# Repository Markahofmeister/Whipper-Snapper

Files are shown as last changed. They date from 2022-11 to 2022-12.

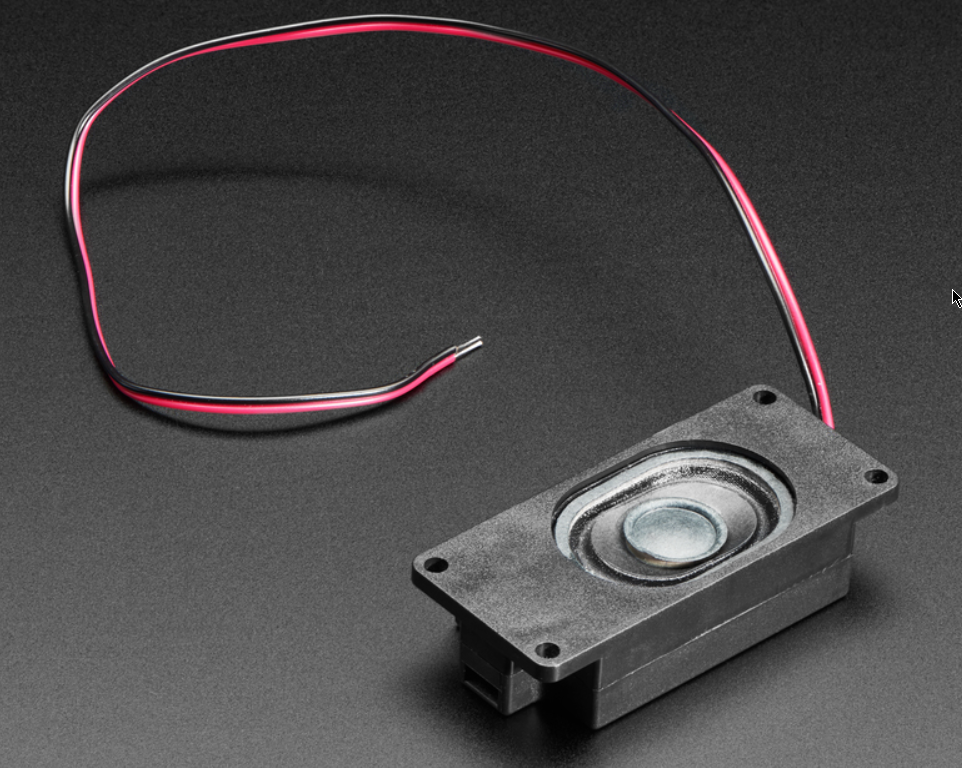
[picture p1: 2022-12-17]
media/3W-speaker.png

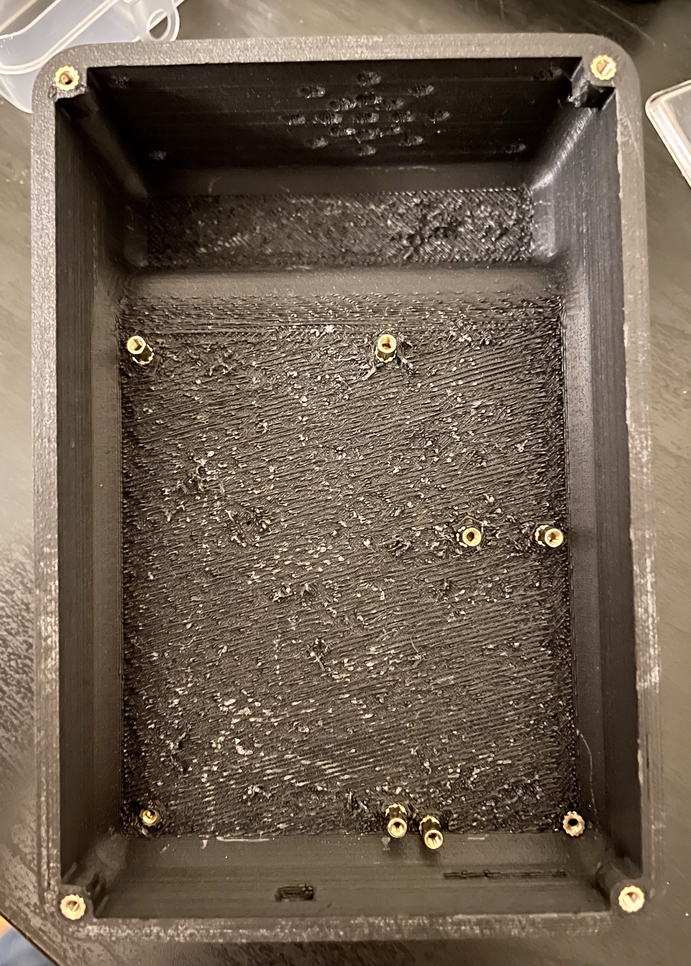
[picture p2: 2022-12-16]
media/standoffs.jpg

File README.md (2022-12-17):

# Whipper-Snapper

```bash
├───fab                     //includes mechanical fabrication .stl and .step
│   └───imported
├───figures                 //diagrams and datasheets
├───media                   //images & videos
├───software                //all Arduino code
│   ├───I2S-test-mono
│   ├───I2S-test-WAV
│   ├───src                 //main code on Arduino
│   └───wav-files
└───Whipper-Snapper-PCB     //All Altium files
```

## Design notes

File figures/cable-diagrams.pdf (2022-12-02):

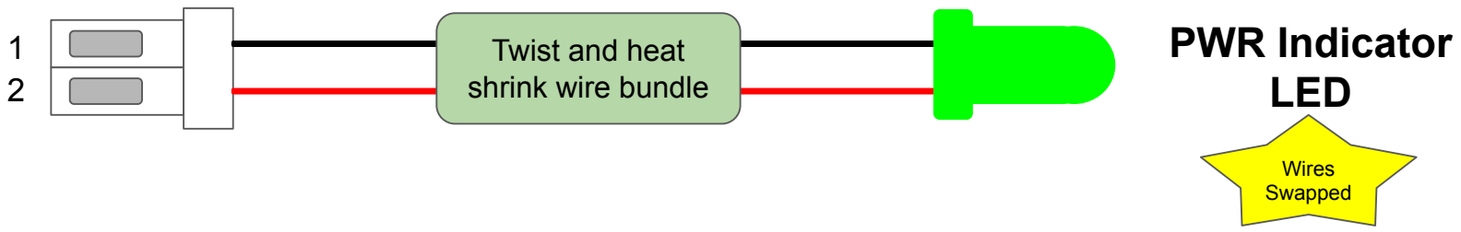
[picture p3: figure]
PWR Indicator LED; Twist and heat shrink wire bundle; Wires Swapped

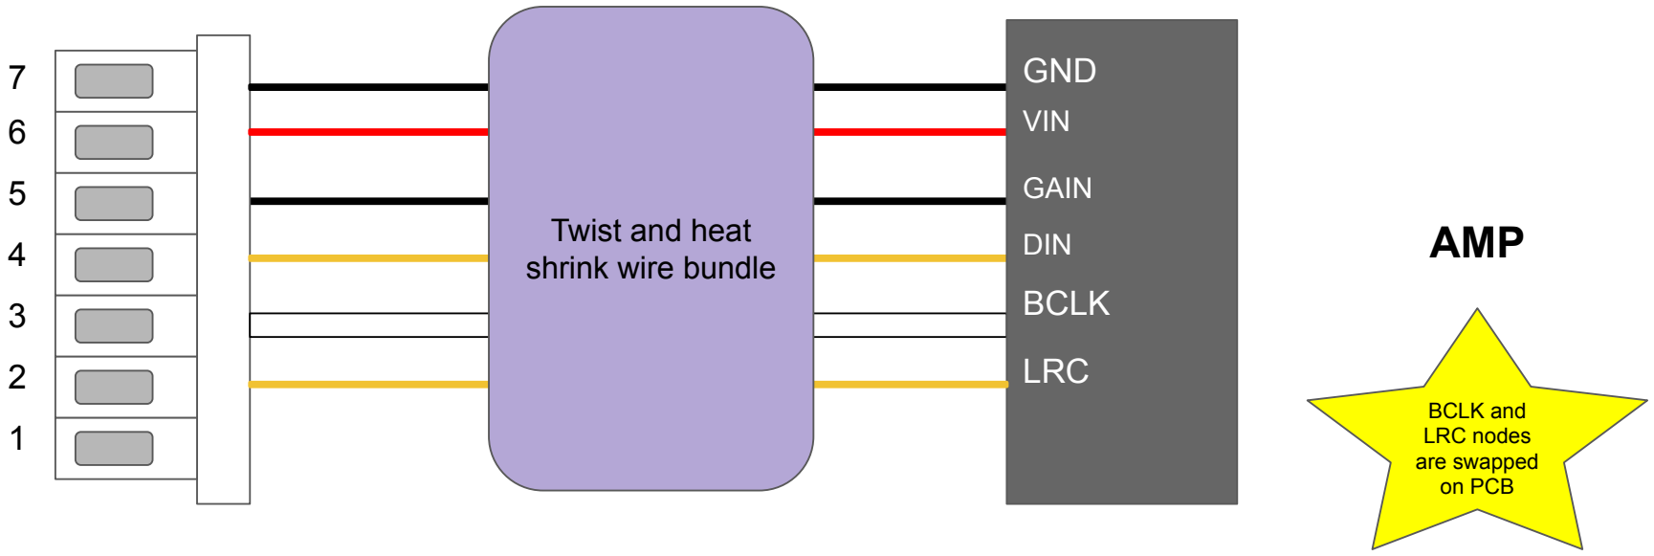
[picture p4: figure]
AMP; GND; LRC; DIN; BCLK; GAIN; VIN; Twist and heat shrink wire bundle; BCLK and LRC nodes are swapped on PCB

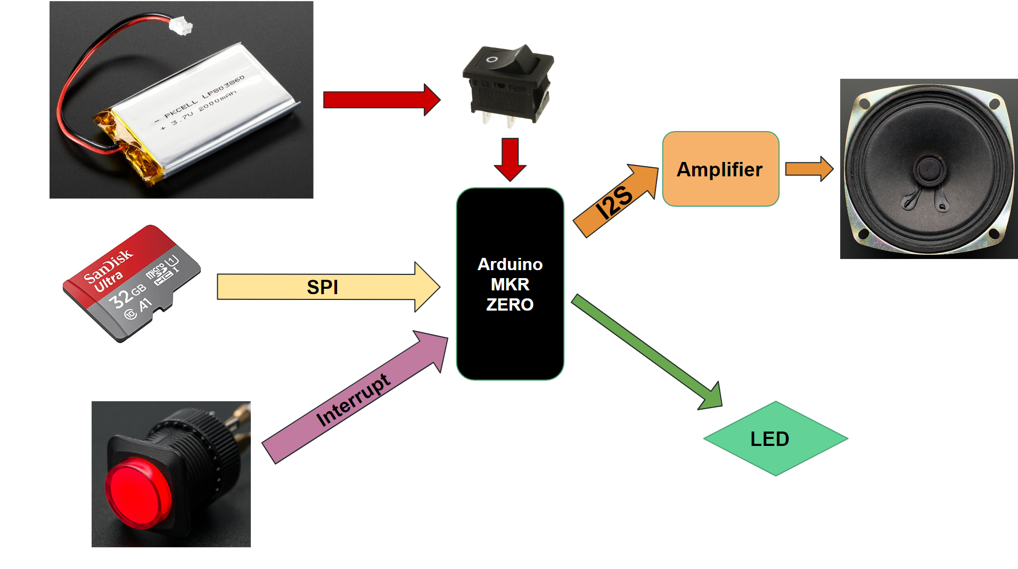
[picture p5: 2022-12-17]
figures/system-diagram.png

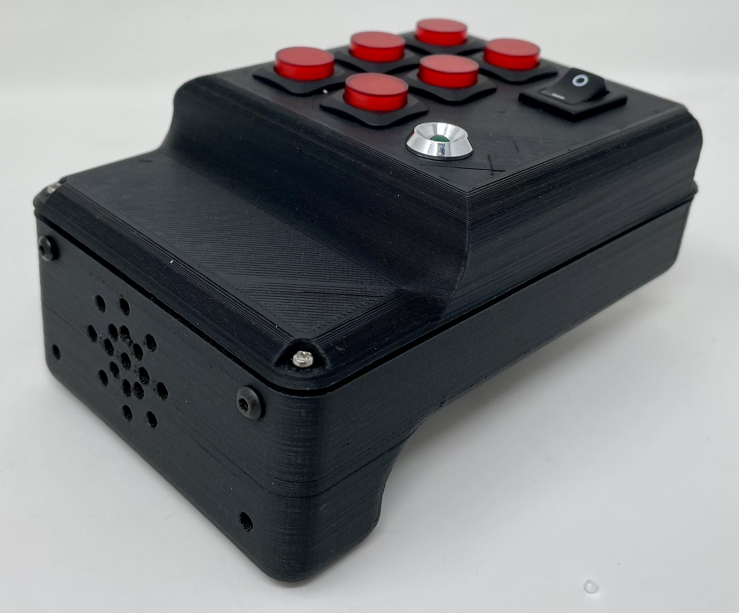
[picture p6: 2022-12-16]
media/final-2.jpg

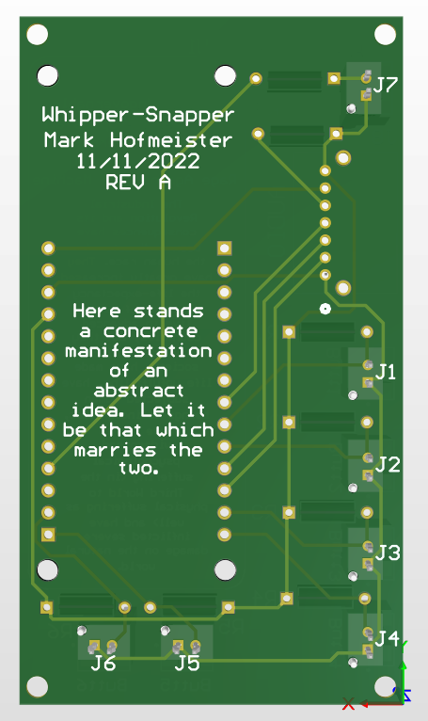
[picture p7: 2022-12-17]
media/pcb-bottom.png

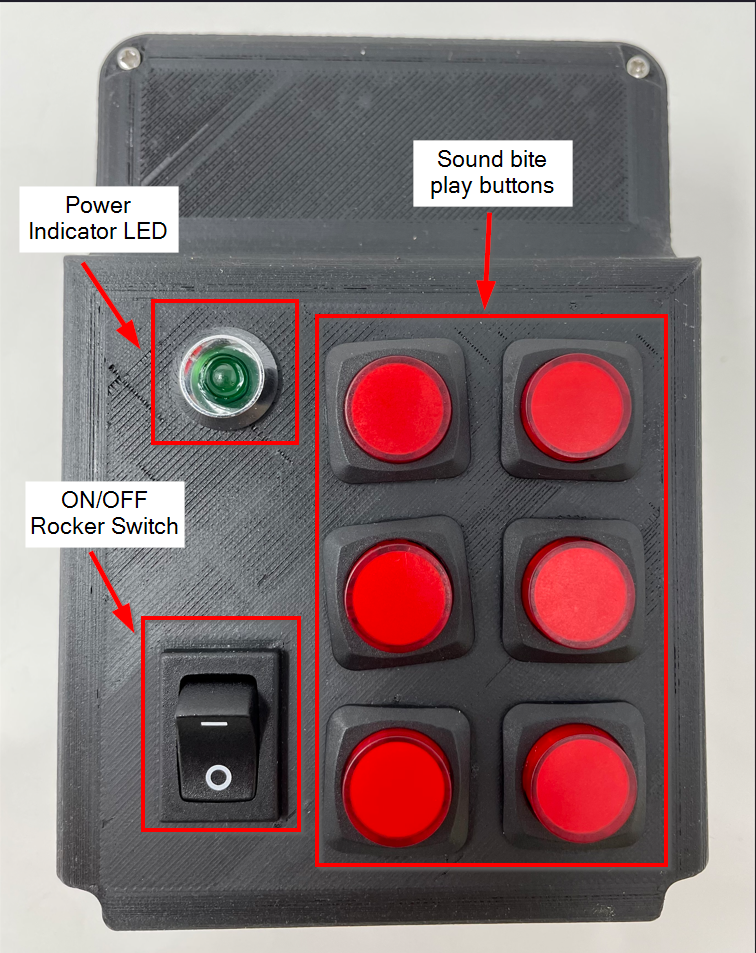
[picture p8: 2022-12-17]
media/TUI-annotated.png

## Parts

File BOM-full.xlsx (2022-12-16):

Name/Desc | MFR | MFR P/N | QTY | Price | Vendor Link | Total Price | Assembly Total Price
Rocker Switch | E-Switch | RA1113112R | 1 | $0.67 | https://www.digikey.com/en/products/detail/e-switch/RA1113112R/3778055 | $0.67 | $113.07
26 AWG Wire, Red | CNC Tech | 1569-26-1-0500-004-1-TS | 1 | $0.47 | https://www.digikey.com/en/products/detail/cnc-tech/1569-26-1-0500-004-1-TS/15853684 | $0.47
26 AWG Wire, Black | CNC Tech | 1569-26-1-0500-001-1-TS | 1 | $0.47 | https://www.digikey.com/en/products/detail/cnc-tech/1569-26-1-0500-001-1-TS/15853661 | $0.47
27 AWG Wire, White | CNC Tech | 1569-26-1-0500-002-1-TS | 1 | $0.47 | https://www.digikey.com/en/products/detail/cnc-tech/1569-26-1-0500-002-1-TS/15853698 | $0.47
27 AWG Wire, Green | CNC Tech | 1569-26-1-0500-011-1-TS | 1 | $0.47 | https://www.digikey.com/en/products/detail/cnc-tech/1569-26-1-0500-011-1-TS/15903796 | $0.47
28 AWG Wire, Orange | CNC Tech | 3135-26-1-0500-008-1-TS | 1 | $0.47 | https://www.digikey.ca/en/products/detail/cnc-tech/3135-26-1-0500-008-1-TS/15853696 | $0.47
JST Crimp, female, 22-26 AWG | JST | SPHD-001T-P0.5 | 32 | $0.03 | https://www.digikey.com/en/products/detail/jst-sales-america-inc/SPHD-001T-P0-5/608766 | $1.01
Class D Mono I2S Stereo Amplifier | Adafruit | 3006 | 1 | $5.95 | https://www.adafruit.com/product/3006 | $5.95
Mono Speaker - 3W, 4 Ohm | Adafruit | 4445 | 1 | $3.95 | https://www.adafruit.com/product/4445 | $3.95
8GB SD Card | Adafruit | 1294 | 1 | $9.95 | https://www.adafruit.com/product/1294 | $9.95
3.7V Lithium Ion Battery - 2000mAh | Adafruit | 2011 | 1 | $12.50 | https://www.adafruit.com/product/2011 | $12.50
16mm Illuminated Push Button - Red Momentary | Adafruit | 1439 | 6 | $1.50 | https://www.adafruit.com/product/1439 | $9.00
USB LiPoly Battery Charger | Adafruit | 259 | 1 | $12.50 | https://www.adafruit.com/product/259 | $12.50
Micro LiPo USB Charger | Adafruit | 1304 | 1 | $5.95 | https://www.adafruit.com/product/1304 | $5.95
Switch with JST connectors | Adafruit | 3064 | 1 | $2.95 | https://www.adafruit.com/product/3064 | $2.95
Arduino MKR Zero | Arduino | - | 1 | $30.30 | https://store-usa.arduino.cc/products/arduino-mkr-zero-i2s-bus-sd-for-sound-music-digital-audio-data | $30.30
Mirco SD Card Extender | UCTRONICS | - | 1 | $15.99 | https://www.amazon.com/UCTRONICS-Flexible-Extension-Compatible-Raspberry/dp/B09CKRDFTH | $15.99
M2 Heat-Set Knurled Threaded Inserts | - | - | 1 |  | https://www.amazon.com/AIEX-Printing-Embedment-Automotive-M2x3x3-5mm/dp/B0B8GN63S2/
M2 Standoffs | - | - | 1 |  | https://www.amazon.com/HELIFOUNER-Spacers-Standoffs-Assortment-Tweezers/dp/B09F8TCLRY/
5mm Chromed Wide Concave Bevel LED Holder | Adafruit | 2178 | 1 | $0.99 | https://www.adafruit.com/product/2178

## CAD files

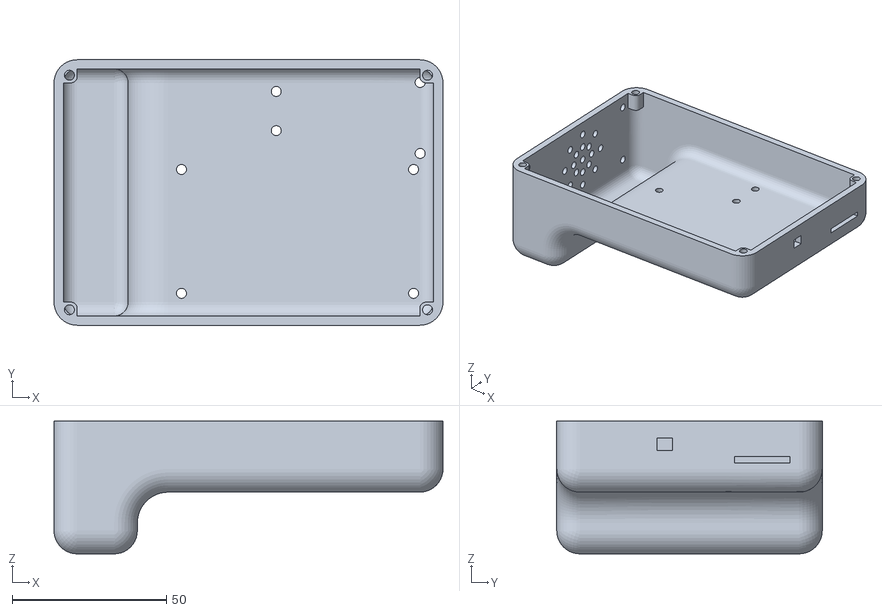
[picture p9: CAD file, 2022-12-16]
fab/base-v2.stl
126.0 x 86.0 x 43.0

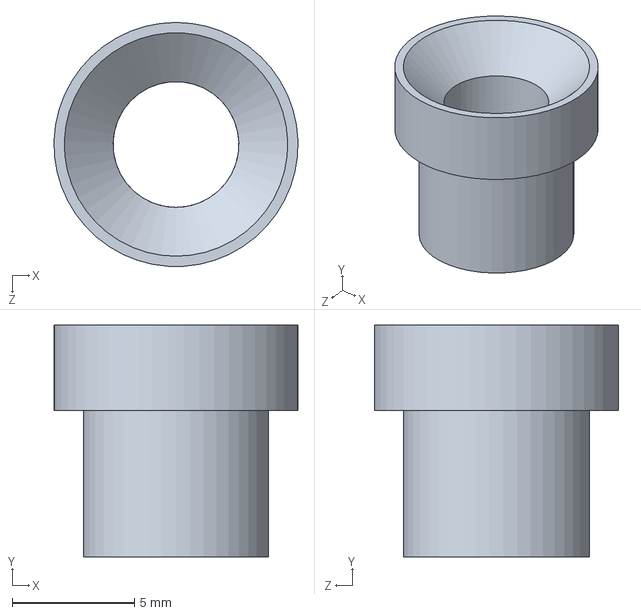
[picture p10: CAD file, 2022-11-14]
fab/imported/led holder.SLDPRT
9.99 x 9.50 x 10.0 mm

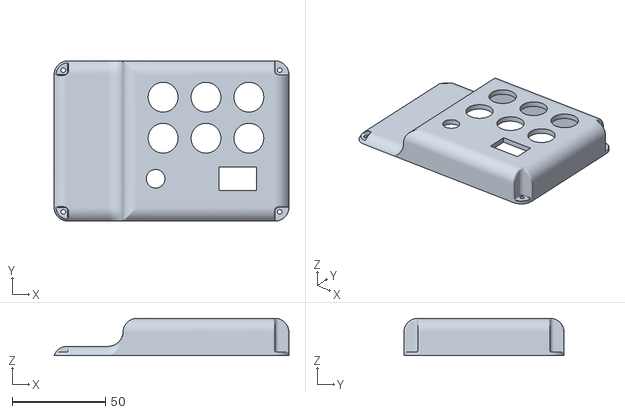
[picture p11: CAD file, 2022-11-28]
fab/hood-v2.stl
126.0 x 86.0 x 20.0

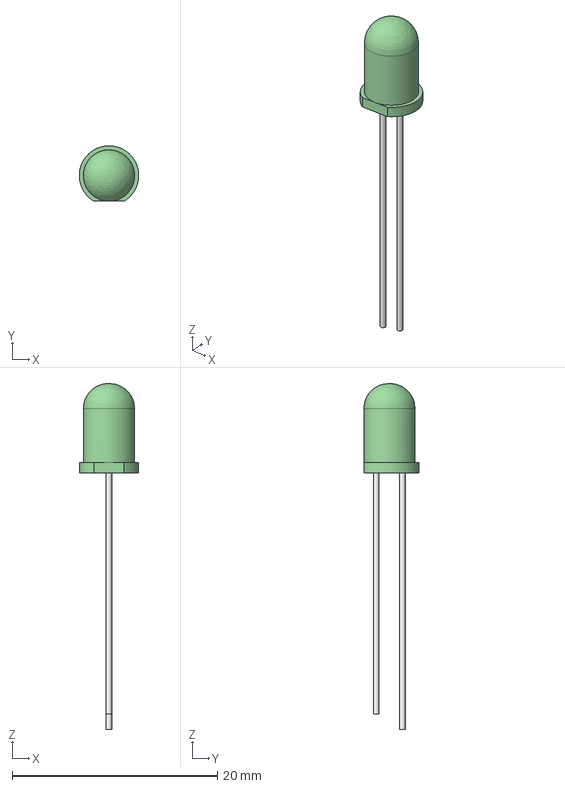
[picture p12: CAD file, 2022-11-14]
fab/imported/LED 5mm green.step
5.79 x 5.40 x 33.7 mm
Leuchtkörper 5mm
Anode
Kadode

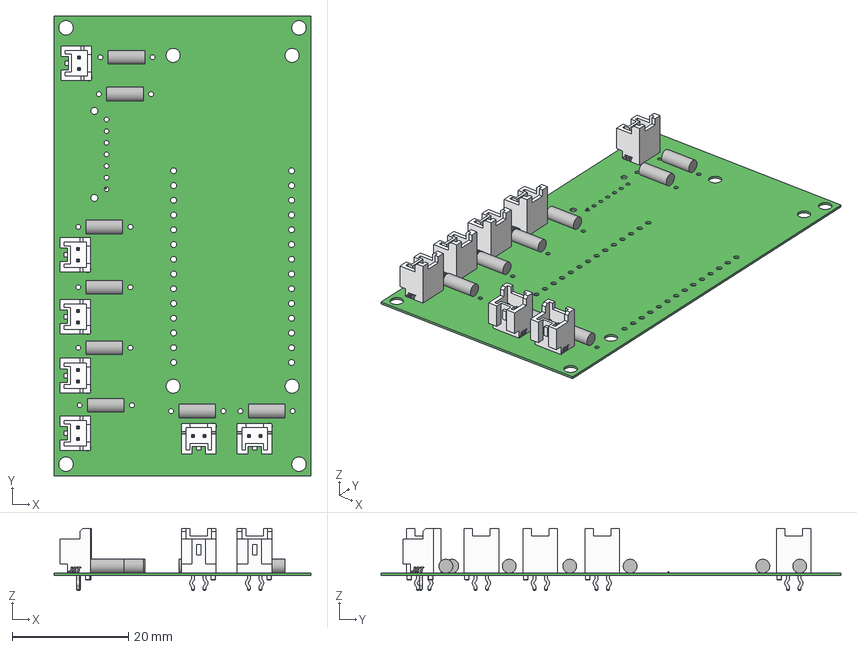
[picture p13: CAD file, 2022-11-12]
fab/imported/IO-PCB.step
44.2 x 79.2 x 10.7 mm
Extruded
B02B-PASK-1 x 7

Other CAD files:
fab/base.step
fab/hood.step
fab/imported/3006 MAX98357.f3d
fab/imported/Momentary Push Button - Red v2.f3d
fab/imported/rocker-switch.f3d

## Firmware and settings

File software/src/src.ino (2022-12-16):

/**
 * src.ino
 * Author: Mark Hofmeister 
 * Created: 11/19/2022
 * Last commit: 12/2/2022
 * 
 * source code for Whipper-Snapper. Reads SD card files, initializes I2S output, and waits to enter interrupt service routines. 
 */
#include <SD.h>                             //Used to read .wav files on SD card
#include <ArduinoSound.h>                   //Used for I2S output 

uint8_t numFiles = 6;

uint8_t interruptPins[] =                   //Declare pins to be used for external interrupts
{  0, 1, 4, 
   5, 6, 7  };

uint8_t pwrLED = 9;                         //LED will indicate when all files have been intialized successfully. 
  
const char fileNames[][6] =                 //Define array of character strings for wave file obect initialization
{  "0.WAV", 
   "1.WAV", 
   "2.WAV", 
   "3.WAV", 
   "4.WAV", 
   "5.WAV"  };

SDWaveFile waveFile[6];                       //define array of SDWaveFile objects. This will store objects once they're initialized. 

void playISR0();                              //ISR function prototypes to declare before array initialization 
void playISR1();
void playISR2();
void playISR3();
void playISR4();
void playISR5();

typedef void (*FunctionArray)(void);          //typedef to make an array of functions. This allows us to attach interrupts using a loop. 

FunctionArray ISRs[] = {                      //pointer to array of ISR names 
  playISR0, 
  playISR1,
  playISR2,
  playISR3,
  playISR4,
  playISR5
};

void setup() {

  Serial.begin(9600);                         //Command Serial to initialize and wait 
  //while (!Serial);                            //Wait for Serial monitor to be initialized 
  Serial.println("Serial monitor initialized"); 
  
  Serial.print("Initializing SD card...");      //Ensure that SD card can be read 
  if (!SD.begin()) {
    Serial.println("failed!");                //If SD card cannot be read, hang in dead loop. LED will not illuminate, and user will know that something is wrong. 
    while(1);
  } 
  
  Serial.println("SD Card Initialized");

  for(int i = 0; i < numFiles; i++) {
    
    waveFile[i] = SDWaveFile(fileNames[i]);         //initialize wave file objects based on file names
    
    if(!(waveFile[i])) {                            //check to see if file was initialized successfully
      Serial.print("Wave file ");
      Serial.print(i);
      Serial.println(" is invalid.");
      //while(1);                     
      
    } 
    else if(!(AudioOutI2S.canPlay(waveFile[i]))) {    //check to see if the wave file can be played

      Serial.print("Wave file ");
      Serial.print(i);
      Serial.println(" is unplayable.");
      //while(1);
      
    }
    else {                                            //If .wav file was initialized successfully and can be played, continue on. 
      Serial.print("Wave file ");
      Serial.print(i);
      Serial.println(" successfully Initialized.");
    }
    
  }

  AudioOutI2S.volume(100.0);                         //max volume = 100.0. Some bass issues above ~70.0 volume. 

  pinMode(pwrLED, OUTPUT);

  for(int i = 0; i < numFiles; i++) {               //loop through attaching interrupts to proper ISRs
    
    attachInterrupt(digitalPinToInterrupt(interruptPins[i]),ISRs[i], RISING); 
  
  }

  digitalWrite(pwrLED, HIGH);                       //Write LED HIGH to indicate a successful initialization of all files and interrupt attachments. 
  
}

void loop() {

    //Dead loop. Awaiting ISR triggerings 
  
}

void playISR0() {

  Serial.println("Entered playISR 0");

  if(AudioOutI2S.isPlaying()) {
    
      //do nothing. Let other file play.
      
  } else {                                    //If nothing is playing currently, a new file can be played. 
        
      AudioOutI2S.play(waveFile[0]);  
      
  }
  
}

void playISR1() {
  
  Serial.println("Entered playISR 1");

  if(AudioOutI2S.isPlaying()) {
    
      //do nothing. Let other file play.
      
  } else {                                   //If nothing is playing currently, a new file can be played. 
    
      AudioOutI2S.play(waveFile[1]);  
      
  }
  
}

void playISR2() {

  Serial.println("Entered playISR 2");

  if(AudioOutI2S.isPlaying()) {
    
      //do nothing. Let other file play.
      
  } else {                                  //If nothing is playing currently, a new file can be played. 
    
      AudioOutI2S.play(waveFile[2]);  
      
  }
  
}

void playISR3() {

  Serial.println("Entered playISR 3");

  if(AudioOutI2S.isPlaying()) {
    
      //do nothing. Let other file play.
      
  } else {                                  //If nothing is playing currently, a new file can be played. 
    
      AudioOutI2S.play(waveFile[3]);  
      
  }
  
}

void playISR4() {

  Serial.println("Entered playISR 4");

  if(AudioOutI2S.isPlaying()) {
    
      //do nothing. Let other file play.
      
  } else {                                //If nothing is playing currently, a new file can be played. 
    
      AudioOutI2S.play(waveFile[4]);  
      
  }
  
}

void playISR5() {

  Serial.println("Entered playISR 5");

  if(AudioOutI2S.isPlaying()) {
    
      //do nothing. Let other file play.
      
  } else {                                //If nothing is playing currently, a new file can be played. 
    
      AudioOutI2S.play(waveFile[5]);  
      
  }
  
}

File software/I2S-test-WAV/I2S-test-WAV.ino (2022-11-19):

/*

 This example generates a square wave based tone at a specified frequency
 and sample rate. Then outputs the data using the I2S interface to a
 MAX98357 I2S Amp Breakout board.
 Circuit:
 * Arduino Zero, MKR family and Nano 33 IoT
 * MAX98357:
   * GND connected GND
   * VIN connected 5V
   * LRC connected to pin 0 (Zero) or 3 (MKR) or A2 (Nano)
   * BCLK connected to pin 1 (Zero) or 2 (MKR) or A3 (Nano)
   * DIN connected to pin 9 (Zero) or A6 (MKR) or 4 (Nano)

 */

#include <SD.h> 
#include <ArduinoSound.h>

const char file1[] = "0.WAV";
SDWaveFile waveFile1;

void setup() {

  Serial.begin(9600);
  while (!Serial);
  Serial.println("Playing .WAV test");
  


   Serial.print("Initializing SD card...");
  if (!SD.begin()) {
    Serial.println("failed!");
  }
  
  Serial.println("SD Card Initialized");
  
  waveFile1 = SDWaveFile(file1);
   if (!waveFile1) {

    Serial.println("wave file is invalid!");

  }

  Serial.print("Bits per sample = ");

  Serial.println(waveFile1.bitsPerSample());

  long channels = waveFile1.channels();

  Serial.print("Channels = ");

  Serial.println(channels);

  long sampleRate = waveFile1.sampleRate();

  Serial.print("Sample rate = ");

  Serial.print(sampleRate);

  Serial.println(" Hz");

  long duration = waveFile1.duration();

  Serial.print("Duration = ");

  Serial.print(duration);

  Serial.println(" seconds");

   AudioOutI2S.volume(100.0);

   if (!AudioOutI2S.canPlay(waveFile1)) {

    Serial.println("unable to play wave file using I2S!");

    while (1); // do nothing

  }

  // start playback

  Serial.println("starting playback");

  AudioOutI2S.play(waveFile1);
}

void loop() {

  // check if playback is still going on

  if (!AudioOutI2S.isPlaying()) {

    // playback has stopped

    Serial.println("playback stopped");

    AudioOutI2S.play(waveFile1);

  }

}

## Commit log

2022-10-31 Add fritzing breadboard
    [MKRZero.fzz]
2022-11-12 Add PCB
    [MKRZero.fzz, Whipper-Snapper-PCB.PrjPcb, pcb.PcbDoc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]
2022-11-12 Add decals
    [pcb.PcbDoc]
2022-11-12 More foolish decals
    [pcb.PcbDoc]
2022-11-12 Add anarchy
    [Whipper-Snapper-PCB.PrjPcb, pcb.PcbDoc, peripherals-headers.SchDoc]
2022-11-12 Add BOM and imported CAD files
    [BOM-full.xlsx, IO-PCB.step, Momentary Push Button - Red v2.f3d]
2022-11-13 Add screws, standoffs, inserts to BOM
    [BOM-full.xlsx]
2022-11-14 Add v1 .stl files and imported component models
    [3006 MAX98357.f3d, BOM-full.xlsx, IO-PCB.step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]
2022-11-14 Fix .stl
    [base-v1.stl, hood-v1.stl]
2022-11-16 Add test sotware, fix fritzing diagrams
    [MKRZero.fzz, base.step, hood.step]
2022-11-18 Fix PCB footprint, .zip for gerber submission
    [Whipper-Snapper-PCB.PrjPcb, pcb.PcbDoc, peripherals-headers.SchDoc]
2022-11-19 Add src code and .wav files. Need to fix code not playing sound bites 1-5
    [I2S-test-WAV.ino, src.ino]
2022-11-28 Lower volume. IDK.
    [Whipper-Snapper-PCB.PrjPcb, hood-v1.stl, hood-v2.stl]
2022-12-02 Change from 6 separate interrupt attachments to a loop with a typedef function pointer
2022-12-02 Add status LED to code, add cable diagram
2022-12-16 Update base .stl file, add media
    [BOM-full.xlsx, base-v1.stl, base-v2.stl]
